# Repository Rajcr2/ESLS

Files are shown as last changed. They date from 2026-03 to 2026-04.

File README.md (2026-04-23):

# Efficient Street Lighting System 

### Introduction

This was my academic project focused on creating a efficient LED based Street Lighting System which will avoid Power Wastage due to manual mismanagement.

### Motivation

I have observed many times that street lights were ON till 10 AM because operator forgot shut the main switch down and seen this very frequently & also lights were ON
1/2 hrs before SUNSET which leads to Power Wastage this is the Main reason or motivation behind this project.

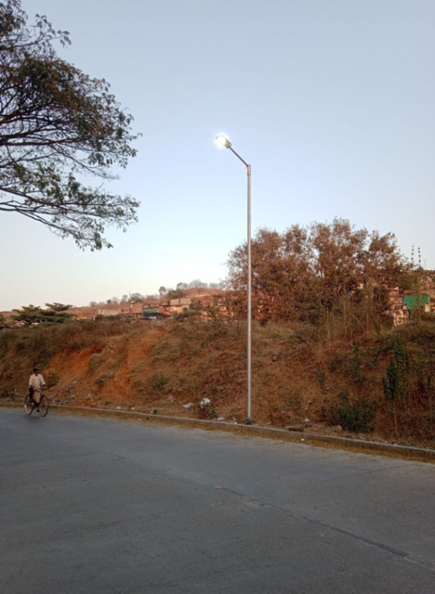
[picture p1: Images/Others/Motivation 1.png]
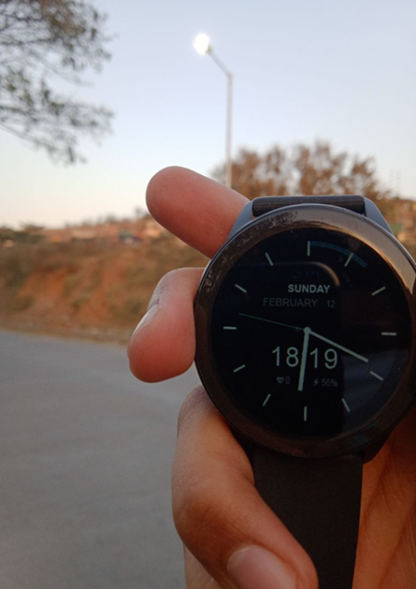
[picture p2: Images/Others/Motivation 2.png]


### Objectives

1.	To make sure that all street lights will remain ON only during **DARK (Cloudy Condition)/NIGHT hours** & will remain off completely during **DAY HOURS (from Sunrise to Sunset)**.
2.	In case, If Power remains ON during Day-Time due to operators negligence LED lights will still remain OFF contributing to Energy saving.
3.	To Improve life of street light lamps.
4.	To Achieve Maximum Energy Efficiency. 

## System Design

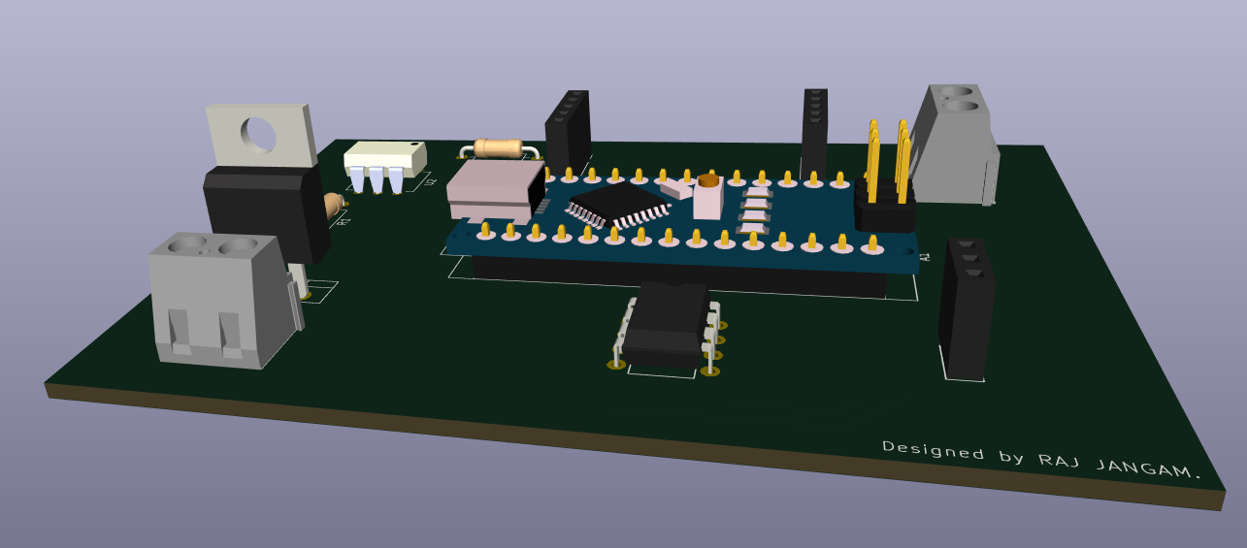
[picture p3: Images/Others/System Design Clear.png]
System Design Clear


### Components

| Component | Purpose |
| --- | --- |
| **Arduino Nano** | Microcontroller control unit |
| **DS1307 - RTC Module** | Time scheduling |
| **MOC3021** | Opto-isolated TRIAC driver |
| **BT136 - TRIAC** | AC load switching |
| **LDR Module** | Detects ambient light intensity (luminance) |
| **470Ω Resistor** | Limits current into optocoupler LED |

### Schematic Design

> The schematic is designed in KiCad. Schematic consists Arduino Nano (Control Unit), DS1307 RTC Module, optocoupler driver (MOC3021), BT136 TRIAC (switching circuit) for AC load along with Resistors.

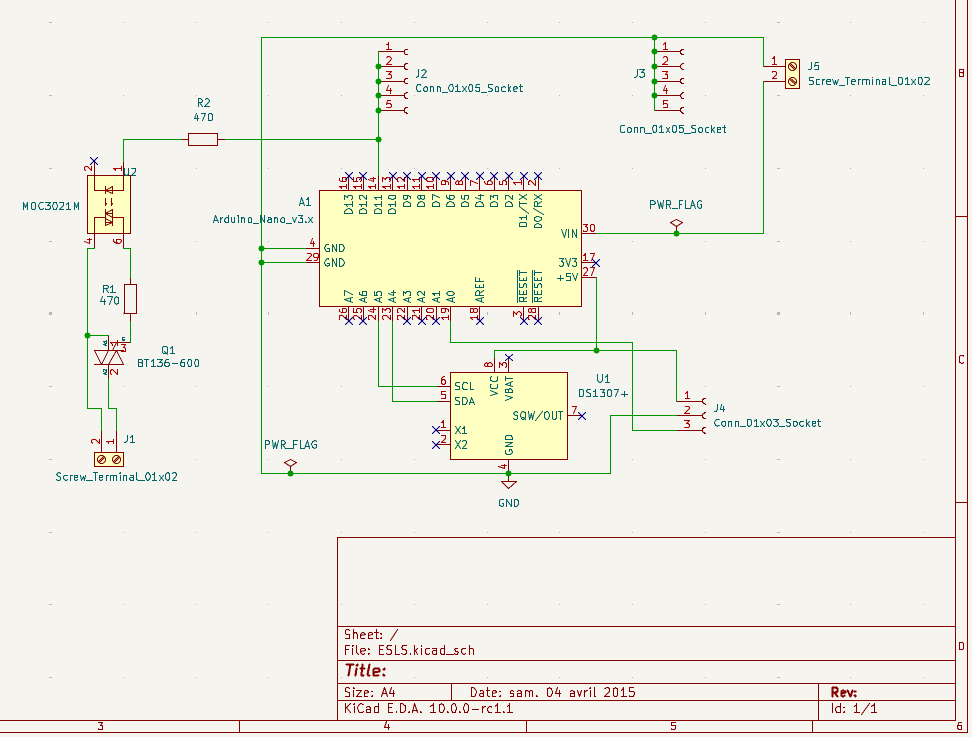
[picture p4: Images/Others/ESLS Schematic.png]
ESLS Schematic


### PCB Layout

> The PCB layout separates the low-voltage control circuitry from the AC power section to maintain electrical isolation. Routing was optimized to keep the power path short and reduce noise coupling.

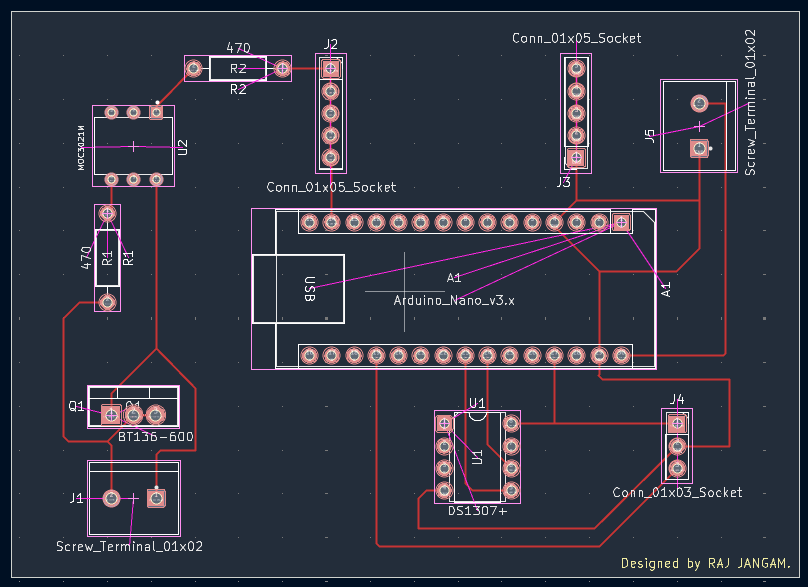
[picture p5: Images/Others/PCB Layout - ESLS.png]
PCB Layout - ESLS


### 3D View

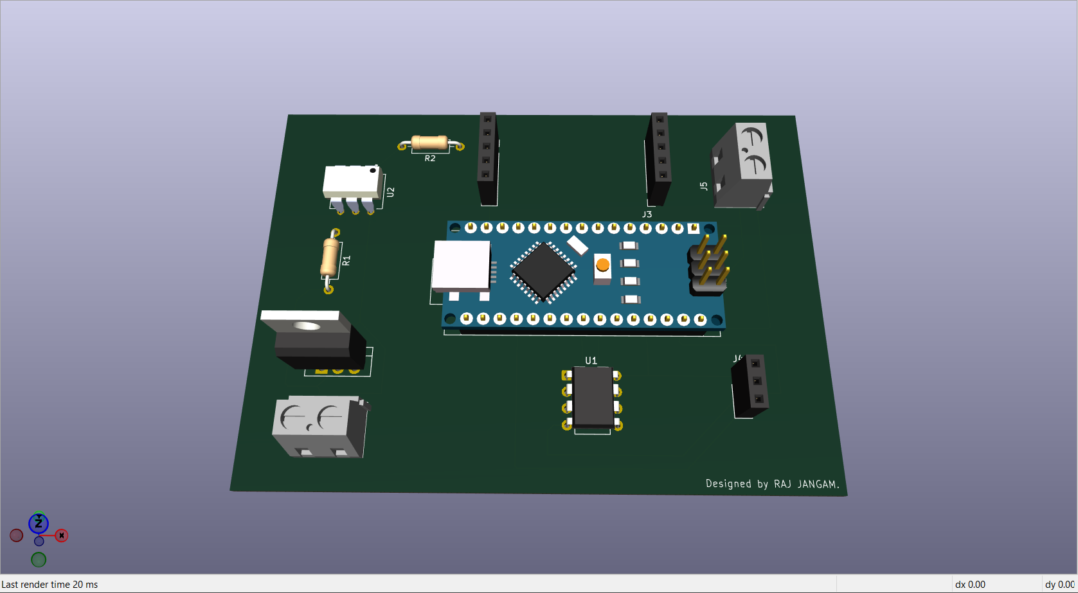
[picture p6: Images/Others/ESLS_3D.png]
ESLS_3D


### Design considerations

- **Isolation between low-voltage control circuit and AC mains section.**  
- **Clear routing of power paths for the TRIAC switching stage.**  
- **Through-hole components used for easier prototyping and soldering.**

## Circuit Simulation

### ngspice Simulation
**Transient analysis** was performed using ngspice integrated in KiCad to validate the Arduino driver stage.

> ### Limitation
> **Since microcontrollers cannot be simulated directly in SPICE, the Arduino PWM output was emulated using a pulse voltage source.**

- ### Simulated Circuit
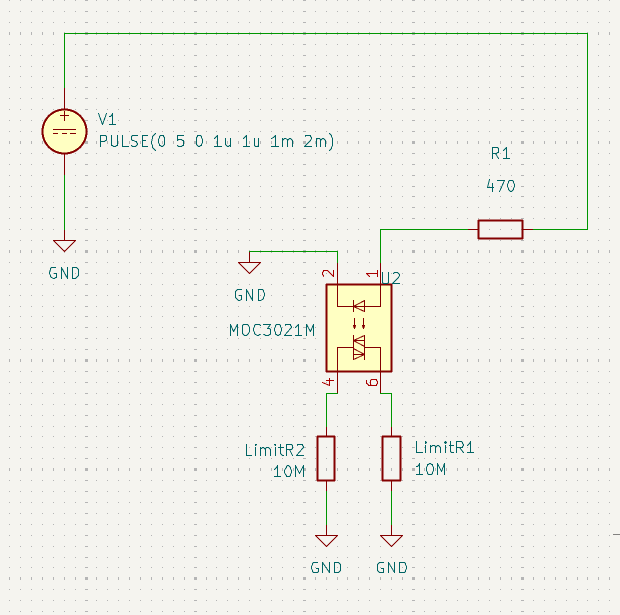
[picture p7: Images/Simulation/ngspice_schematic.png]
ngspice_schematic


- ### PWM Signal Emulation

All required Arduino PWM signals were emulated using the SPICE source :

Example : **PULSE(0 5 0 1u 1u 1m 2m)**
| Parameter | Value |
| --- | ----- |
| Low Voltage  | 0 V |
| High Voltage | 5 V |
| Rise Time | 1 µs |
| Fall Time | 1 µs |
| ON Time | 1 ms  |
| Period | 2 ms  |

This results in a 50% duty cycle PWM signal, which corresponds to the Arduino command:

`analogWrite(pin,128)`

- ### Transient Analysis Results

The transient simulation produced the following waveform.

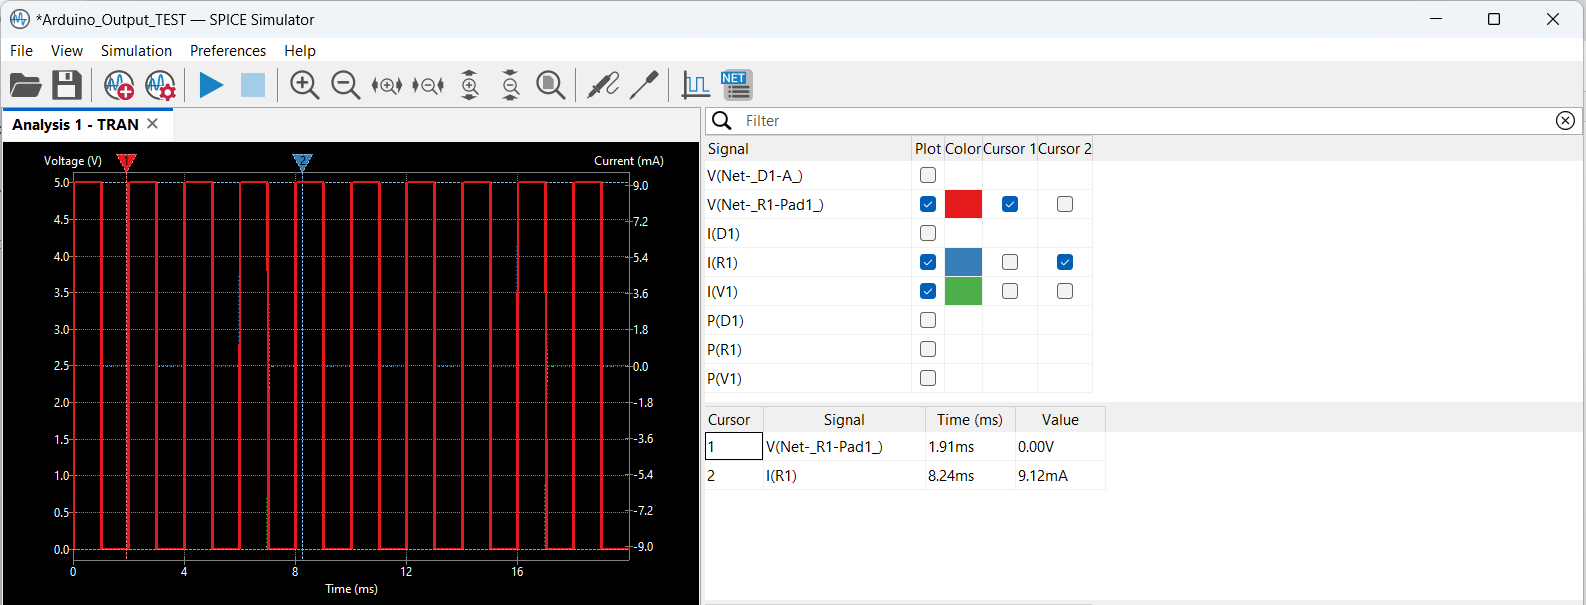
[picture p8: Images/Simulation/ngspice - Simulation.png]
ngspice_simulation


**Observations from the simulation** :
- The voltage waveform alternates between 0 V and 5 V, representing the PWM output.
- The current through the resistor and LED appears as periodic pulses synchronized with the PWM signal.

> **Calculation** :
>
> **I = (Vcc − Vf) / R**
>
> **Vcc** = 5 V, **Vf** ≈ 1.2 V (LED forward voltage), **R** = 470 Ω
>
> I ≈ (5 − 1.2) / 470
> 
> **I ≈ 8 mA**

- **The simulated current (~9.1 mA) aligns with this calculation and confirms that the Arduino output pin can safely drive the optocoupler input stage.**

### Proteus Simulation

To verify the embedded firmware behavior, the system was simulated in **Proteus**.

Unlike SPICE tools, Proteus allows simulation of **Arduino code execution along with peripheral modules such as the RTC**.

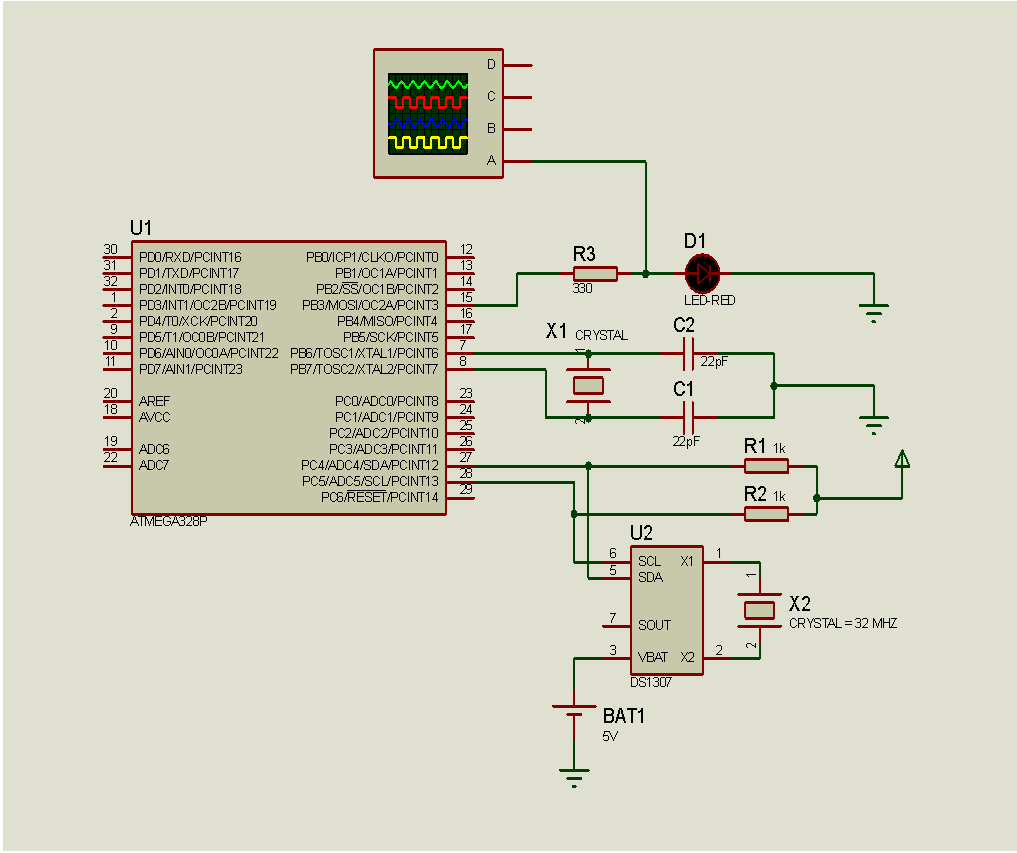
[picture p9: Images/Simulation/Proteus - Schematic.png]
ngspice_simulation


Simulation demonstrates and displays output Oscilloscope how the Arduino program changes the **output signal according to the RTC time conditions**.

### Simulation Outputs

- #### At Mid-Day Time :
  As per our goal light must remain off during Day Time and thats we have achieved. It will only **"Turn ON"** if LDR triggers due to cloudy condition.
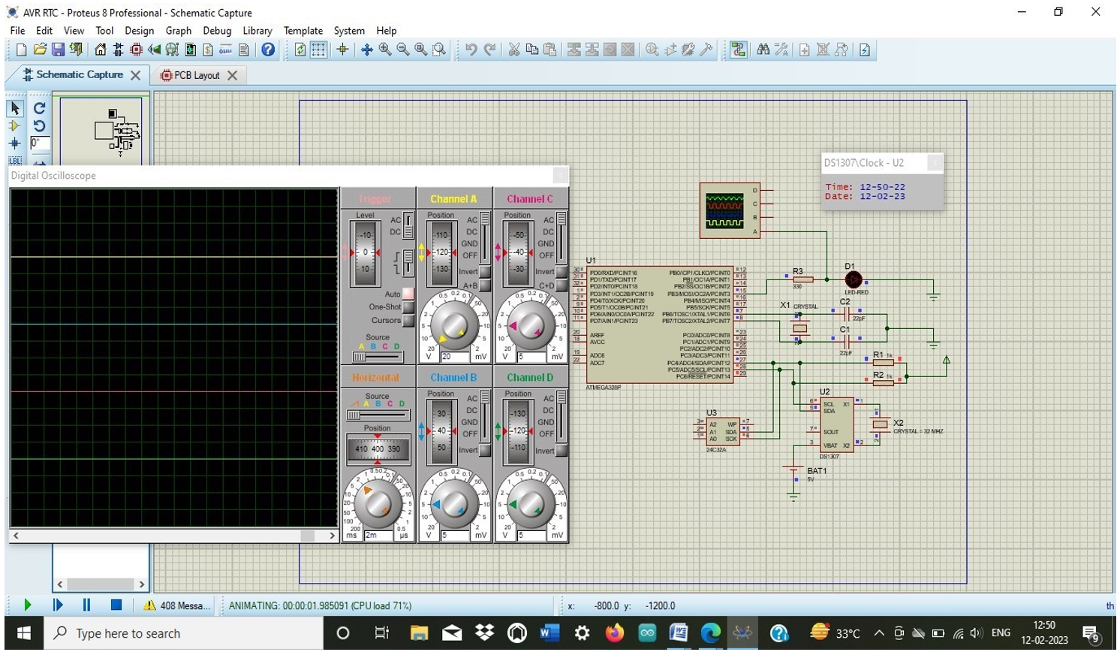
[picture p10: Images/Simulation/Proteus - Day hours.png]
Proteus_Day_Hours


- #### At Evening Time :
  As during sunset time, we need light but, not fully in regular seasons so, 50% light is enough and that we got it. For special case, during cloudy conditions if it senses Darkness around will trigger LDR. so, Both scenarios are covered.
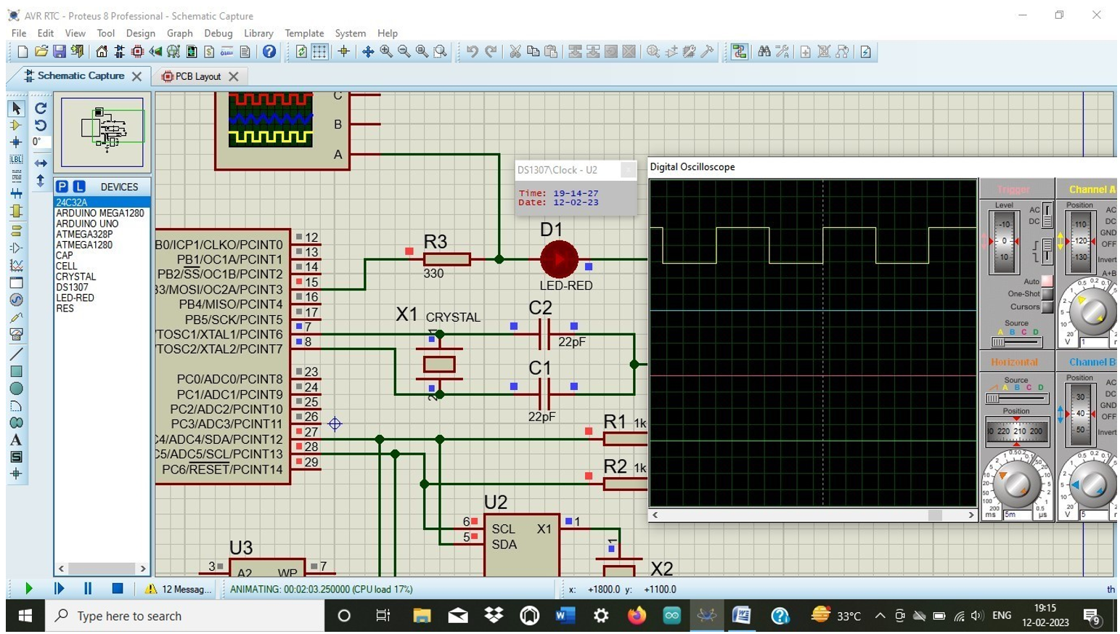
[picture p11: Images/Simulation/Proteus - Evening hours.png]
Proteus_Day_Hours


- #### At Night :
  Light is fully ON.
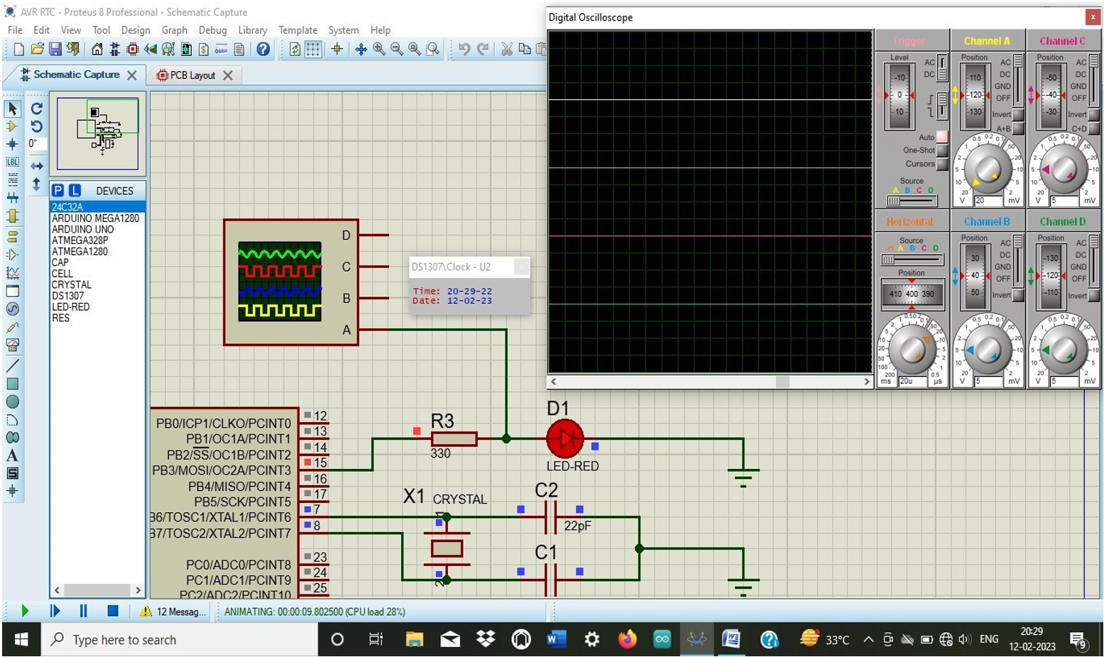
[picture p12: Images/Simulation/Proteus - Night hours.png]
Proteus_Day_Hours


- #### At Early Morning :
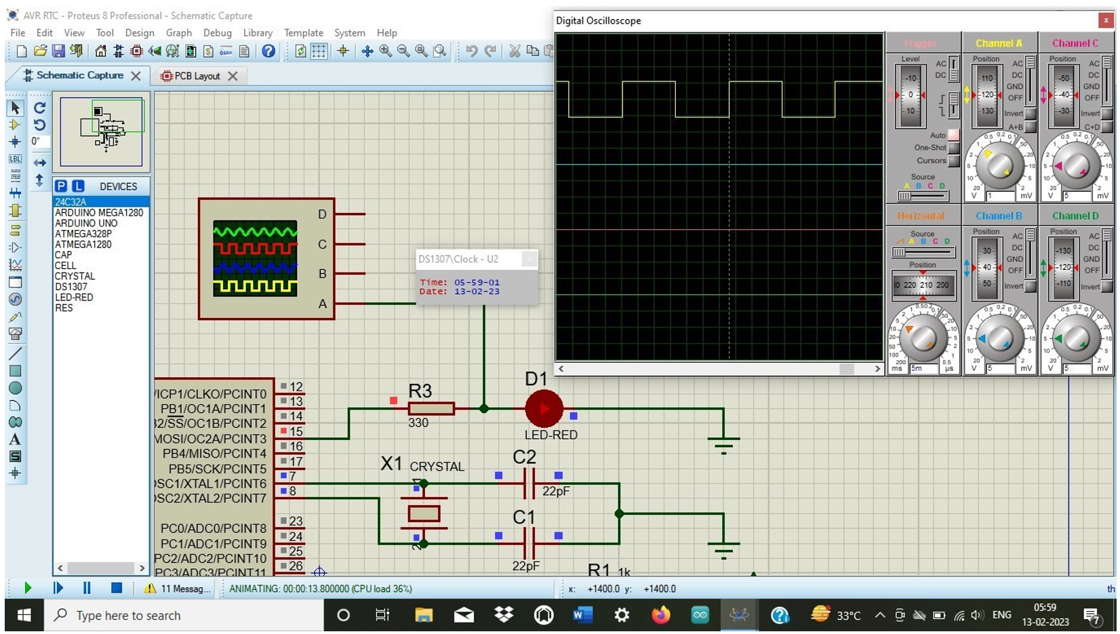
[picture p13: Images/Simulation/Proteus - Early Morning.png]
Proteus_Day_Hours


- #### At Morning
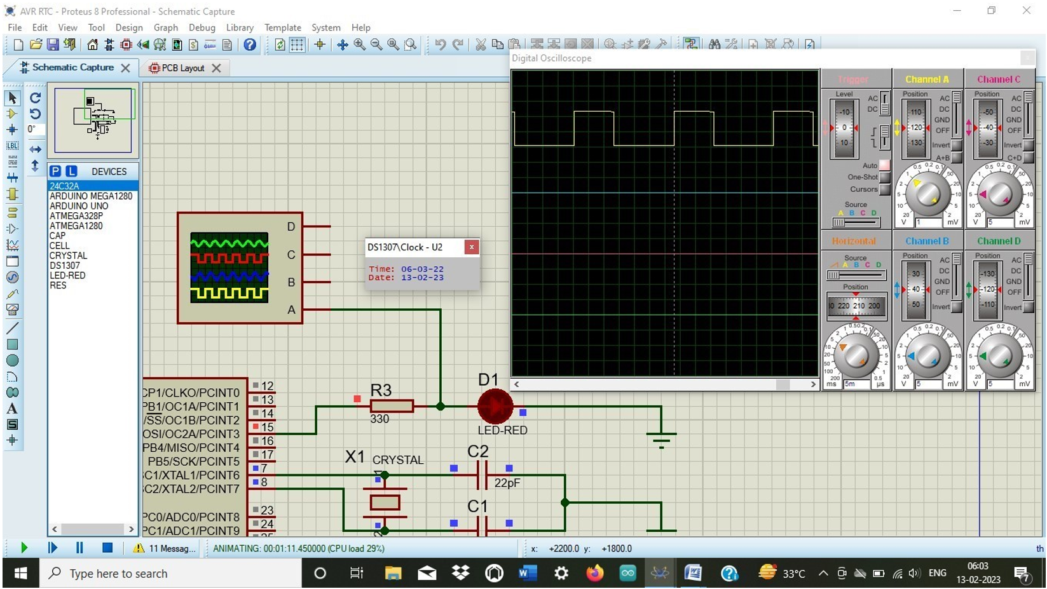
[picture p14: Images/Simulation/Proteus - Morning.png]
Proteus_Day_Hours


These results confirm that the firmware correctly generates the expected control signal based on RTC timing conditions. Using the same logic then implemented and validated on the physical hardware prototype.
__________
## Hardware Implementation

The circuit is implemented on a custom PCB designed in KiCad. 
The circuit board includes the Arduino Nano module, RTC module, LDR sensor module, MOC3021 optocoupler, 470Ω resistor, connectors, and a BT136 TRIAC.

The Arduino Nano is mounted on the PCB and programmed to execute the control logic based on RTC timing conditions. After assembling the PCB, the logic was tested on a working prototype to validate the system behaviour of the control stage.

### PCB
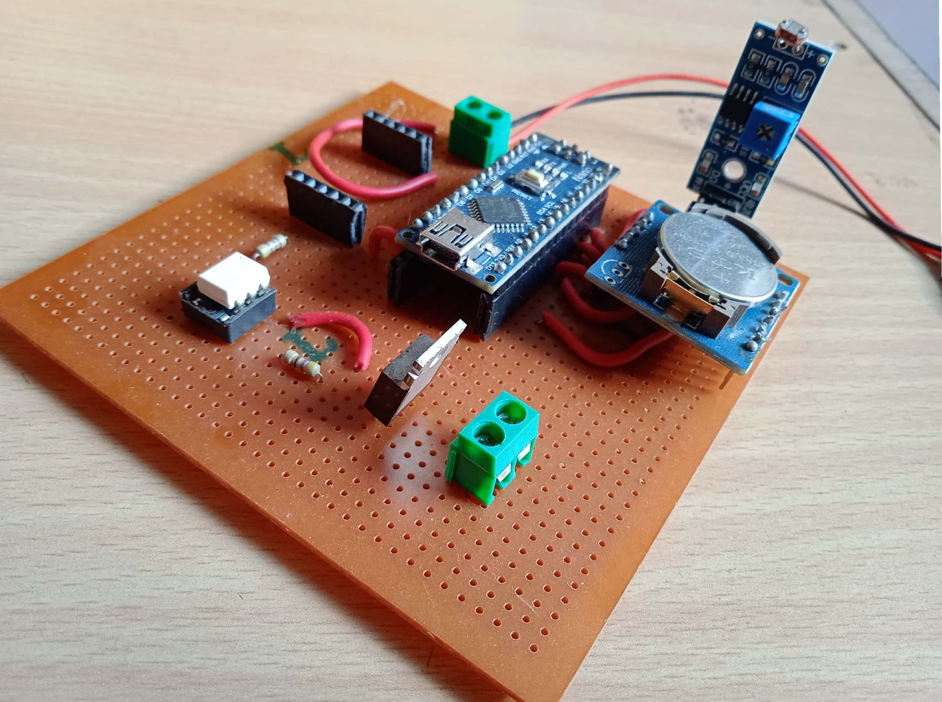
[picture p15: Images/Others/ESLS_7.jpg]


### Prototype


## Results

**The hardware prototype was tested at different time conditions defined in the firmware.
The observed outputs confirm that the system correctly generates the control signal and operates as intended.**

- #### 1. During Day Time
  Mechanism is developed in way that during hours from **8 AM to 6 PM** Light will remain OFF. In case, operator forgot to switch off main switch still lights will be OFF.
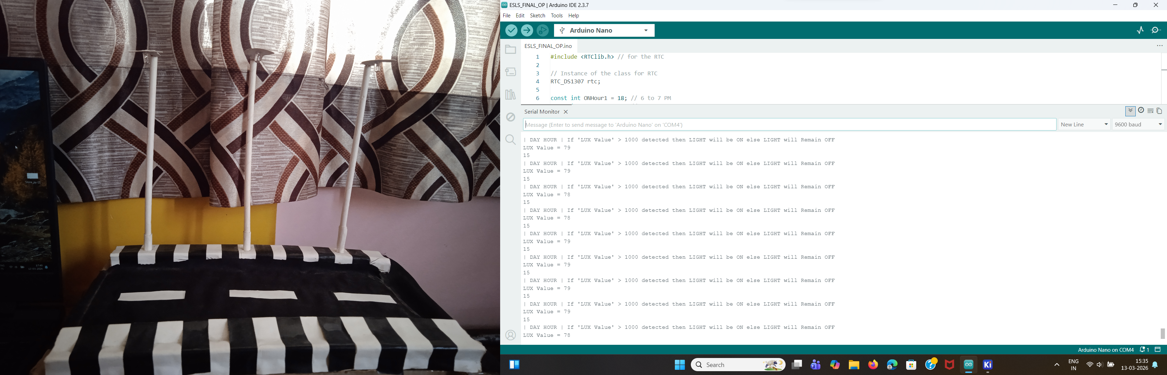
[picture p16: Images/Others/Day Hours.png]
Day Hours


- #### 2. At Evening
  In the evening, during the time of **Sunset** there is enough light present so, we don't need street lights with Full intensity, so we have make   sure that lights will be ON with bit less intensity like at **6-7 PM = 40%** & **7-8 PM = 50%**. Same logic is used during **Sunrise** time as well. 
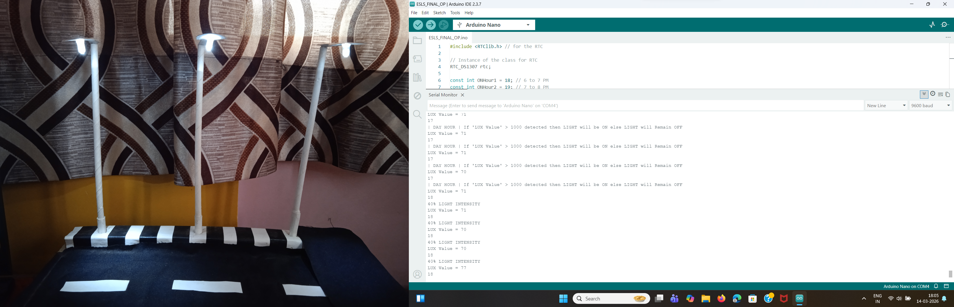
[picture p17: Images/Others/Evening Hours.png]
Evening Hours


- #### 3. At Peak Night Hours
  Only During complete DARK hours mainly from **8 PM to 5 AM** Lights will be ON with Full intensity.
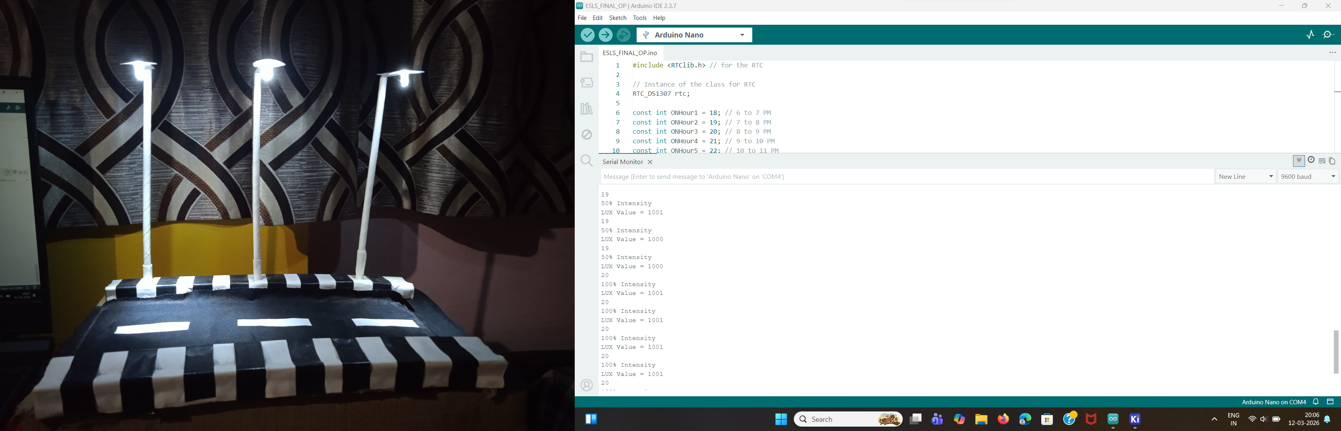
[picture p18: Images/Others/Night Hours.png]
Night Hours


- #### 4. During Cloudy Conditions
  This is a special case designed for Rainy Season, where if clouds appear in Day hours incase if LDR senses surrounding is DARK it will Turn ON lights Automatically without any need Manual workers risking their life in Rainy times.
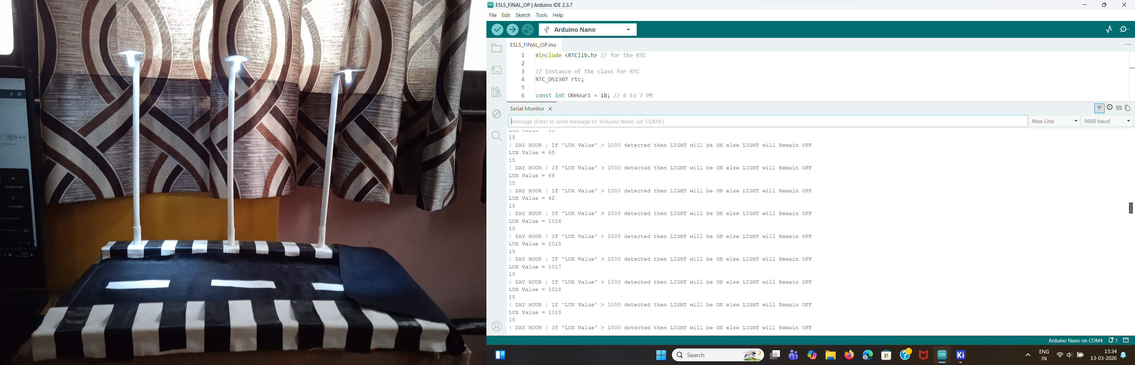
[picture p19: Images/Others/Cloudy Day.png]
Cloudy


## Conclusion
Developed a system that will use **RTC (Real Time Clock) and surrounding ambience with LDR Sensor** intelligently and will make sure Light will be **ON only during DARK Hours** in case of **DAY Hours it will be ON but, with less intensity**. Which will,
- **Improve life of Street Lights.**
- **Contribute to lot of Energy Savings.**

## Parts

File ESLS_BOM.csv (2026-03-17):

Reference | Qty | Value | DNP | Exclude from BOM | Exclude from Board | Footprint | Datasheet
A1 | 1 | Arduino_Nano_v3.x |  |  |  | Module:Arduino_Nano | http://www.mouser.com/pdfdocs/Gravitech_Arduino_Nano3_0.pdf
J1,J5 | 2 | Screw_Terminal_01x02 |  |  |  | SnapEDA:TE_282837-2
J2,J3 | 2 | Conn_01x05_Socket |  |  |  | Connector_PinSocket_2.54mm:PinSocket_1x05_P2.54mm_Vertical
J4 | 1 | Conn_01x03_Socket |  |  |  | Connector_PinSocket_2.54mm:PinSocket_1x03_P2.54mm_Vertical
Load1 | 1 | 500 |  |  |  | Resistor_THT:R_Axial_DIN0207_L6.3mm_D2.5mm_P10.16mm_Horizontal
Q1 | 1 | BT136-600 |  |  |  | Package_TO_SOT_THT:TO-220-3_Vertical | http://www.micropik.com/PDF/BT136-600.pdf
R1,R2 | 2 | 470 |  |  |  | Resistor_THT:R_Axial_DIN0207_L6.3mm_D2.5mm_P10.16mm_Horizontal
U1 | 1 | DS1307+ |  |  |  | Package_DIP:DIP-8_W7.62mm | https://datasheets.maximintegrated.com/en/ds/DS1307.pdf
U2 | 1 | MOC3021M |  |  |  | SnapEDA:DIP762W45P254L889H508Q6_MOC3021 | https://www.onsemi.com/pub/Collateral/MOC3023M-D.PDF
V1 | 1 | VSIN |  |  |  |  | https://ngspice.sourceforge.io/docs/ngspice-html-manual/manual.xhtml#sec_Independent_Sources_for
V2 | 1 | 5 |  |  |  |  | https://ngspice.sourceforge.io/docs/ngspice-html-manual/manual.xhtml#sec_Independent_Sources_for

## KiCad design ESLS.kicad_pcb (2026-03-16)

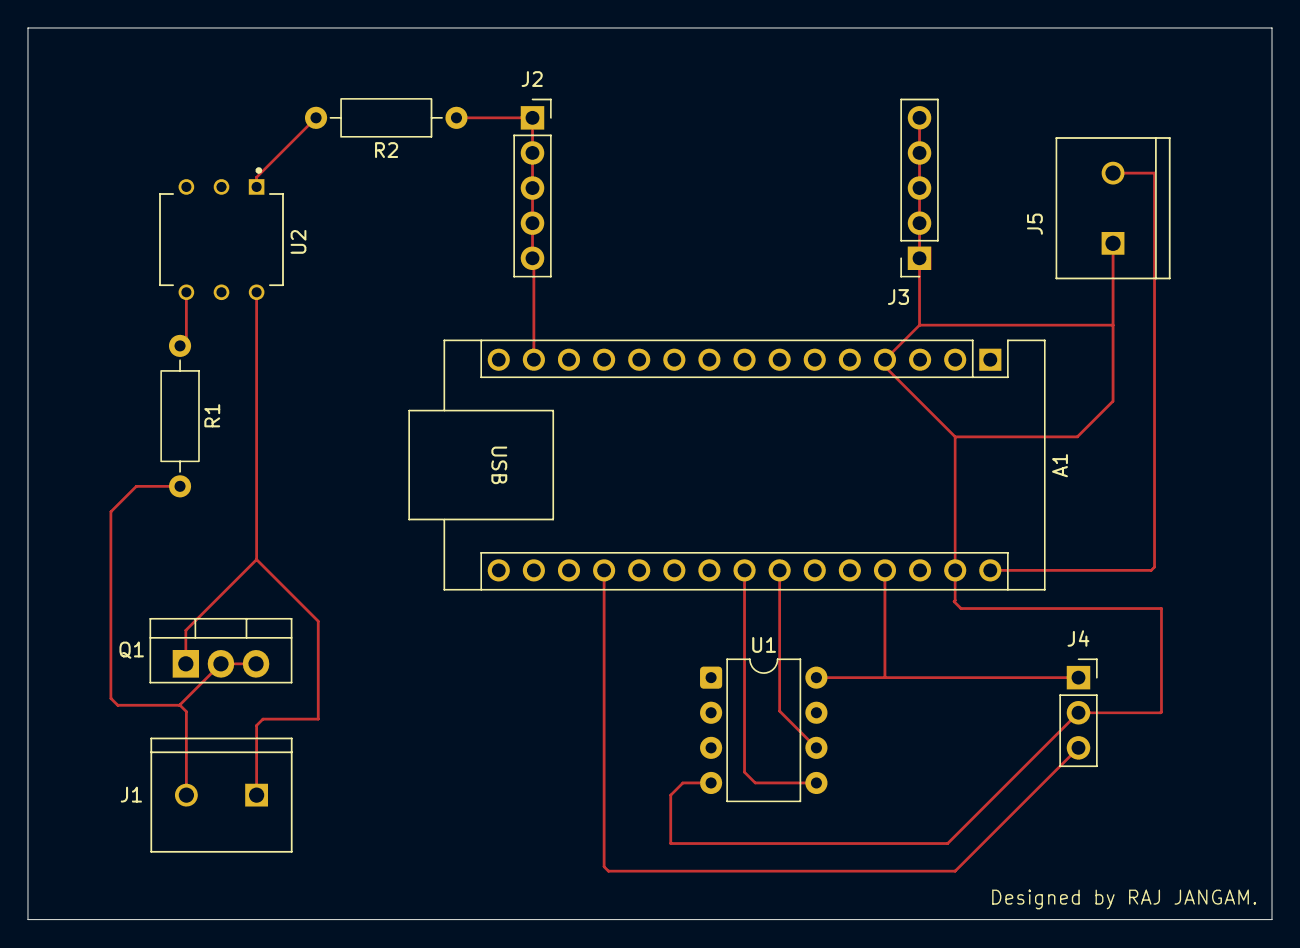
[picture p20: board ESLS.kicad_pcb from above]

Board: 2 copper layers, 90.0 x 64.5 mm, 11 parts (0 on the bottom side), 11 nets.

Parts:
A1: Arduino_Nano_v3.x; Arduino_Nano
J1, J5: Screw_Terminal_01x02; TE_282837-2
J2, J3: Conn_01x05_Socket; PinSocket_1x05_P2.54mm_Vertical
J4: Conn_01x03_Socket; PinSocket_1x03_P2.54mm_Vertical
Q1: BT136-600; TO-220-3_Vertical
R1, R2: 470; R_Axial_DIN0207_L6.3mm_D2.5mm_P10.16mm_Horizontal
U1: DS1307+; DIP-8_W7.62mm
U2: MOC3021M; DIP762W45P254L889H508Q6_MOC3021

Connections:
GND: A1.4 (GND), A1.29 (GND), J3.1, J3.2, J3.3, J3.4, J3.5, J4.2, J5.1, U1.4 (GND)
unnamed: A1.27 (+5V), J4.1, U1.8 (VCC)
unnamed: A1.19 (A0), J4.3
unnamed: A1.23 (A4), U1.5 (SDA)
unnamed: A1.24 (A5), U1.6 (SCL)
unnamed: A1.14 (D11), J2.1, J2.2, J2.3, J2.4, J2.5, R2.1
unnamed: A1.30 (VIN), J5.2
unnamed: J1.1, Q1.1 (A1), U2.6
unnamed: J1.2, Q1.2 (A2), Q1.3 (G), R1.2
unnamed: R1.1, U2.4
unnamed: R2.2, U2.1
